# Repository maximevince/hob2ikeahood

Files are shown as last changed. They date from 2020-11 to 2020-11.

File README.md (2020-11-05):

# hob2ikeahood

## What is it?

AEG hob2hood support for Ikea Underverk Hoods

AEG hob2hood sends infrared codes from the hob in your kitchen to the hood on top of it.
E.g. AEG IKB84401FB supports this. (https://www.aeg.co.uk/kitchen/cooking/hobs/induction-hob/ikb84401fb/)

I do not have the appropriate AEG hood, that supports the hob2hood function, but rather a cheaper Ikea "Underverk"
(https://www.ikea.com/gb/en/p/underverk-built-in-extractor-hood-stainless-steel-50392326/)

## How does it work?

This project consists of a small PCB with some Arduino firmware, which will add hob2hood support to the Ikea Underverk.
It can be connected to sit in between the existing mainboard, and the buttons PCB. This way, no existing functionality is compromised.
You can still use the manual buttons, if you'd like to.

This is what the PCB looks like:

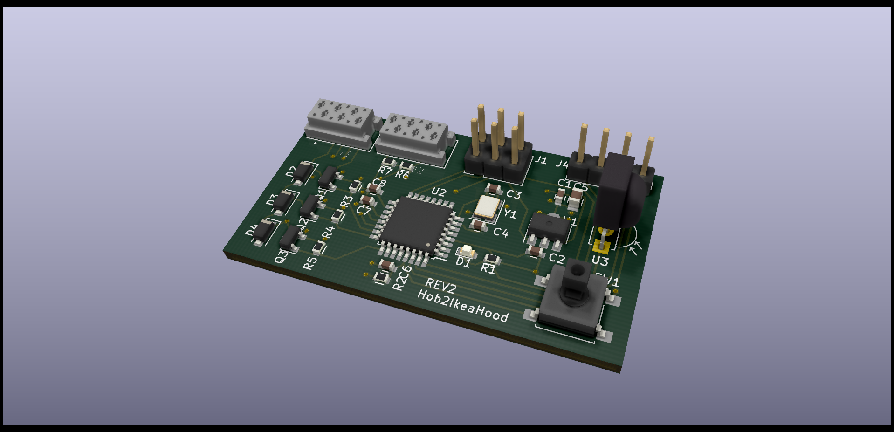
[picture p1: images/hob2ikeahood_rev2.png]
hob2ikeahood rev2 PCB


And this is what it looks like, when installed:

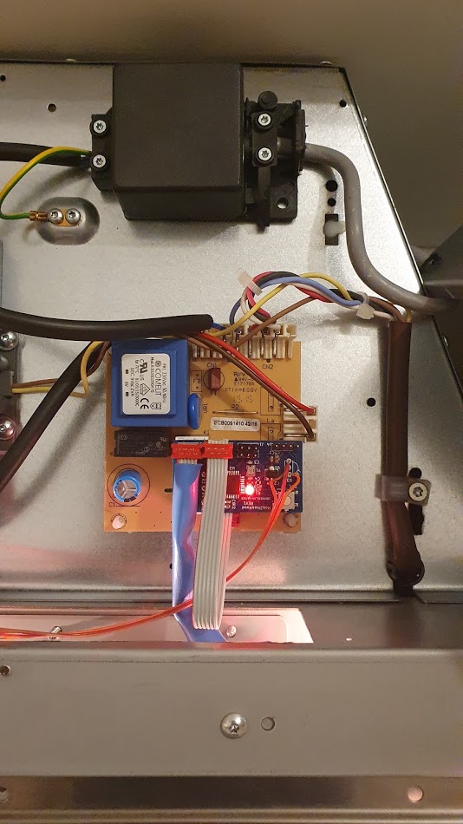
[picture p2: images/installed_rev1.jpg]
hob2ikeahood rev1 installed


A bit closer:

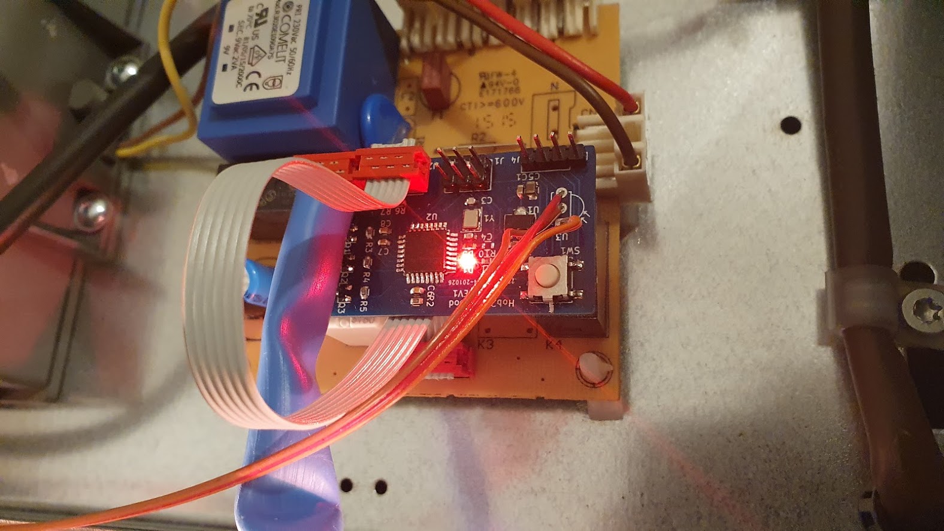
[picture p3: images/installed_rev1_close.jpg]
hob2ikeahood rev1 close-up


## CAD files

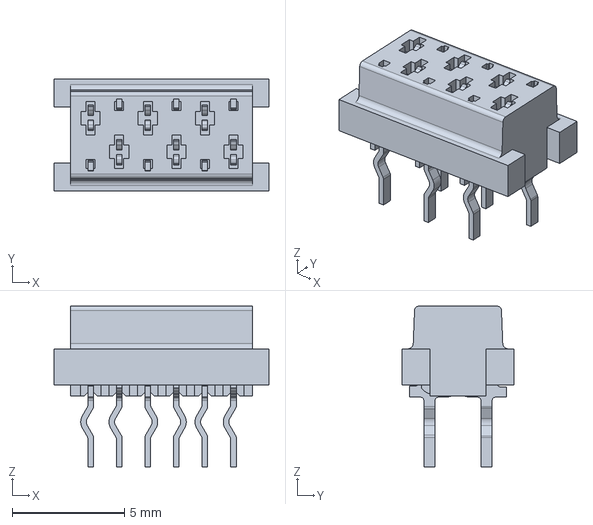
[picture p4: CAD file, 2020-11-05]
hardware/hob2hood.3dmodels/c-215079-6-t-3d.stp
9.56 x 5.00 x 7.15 mm

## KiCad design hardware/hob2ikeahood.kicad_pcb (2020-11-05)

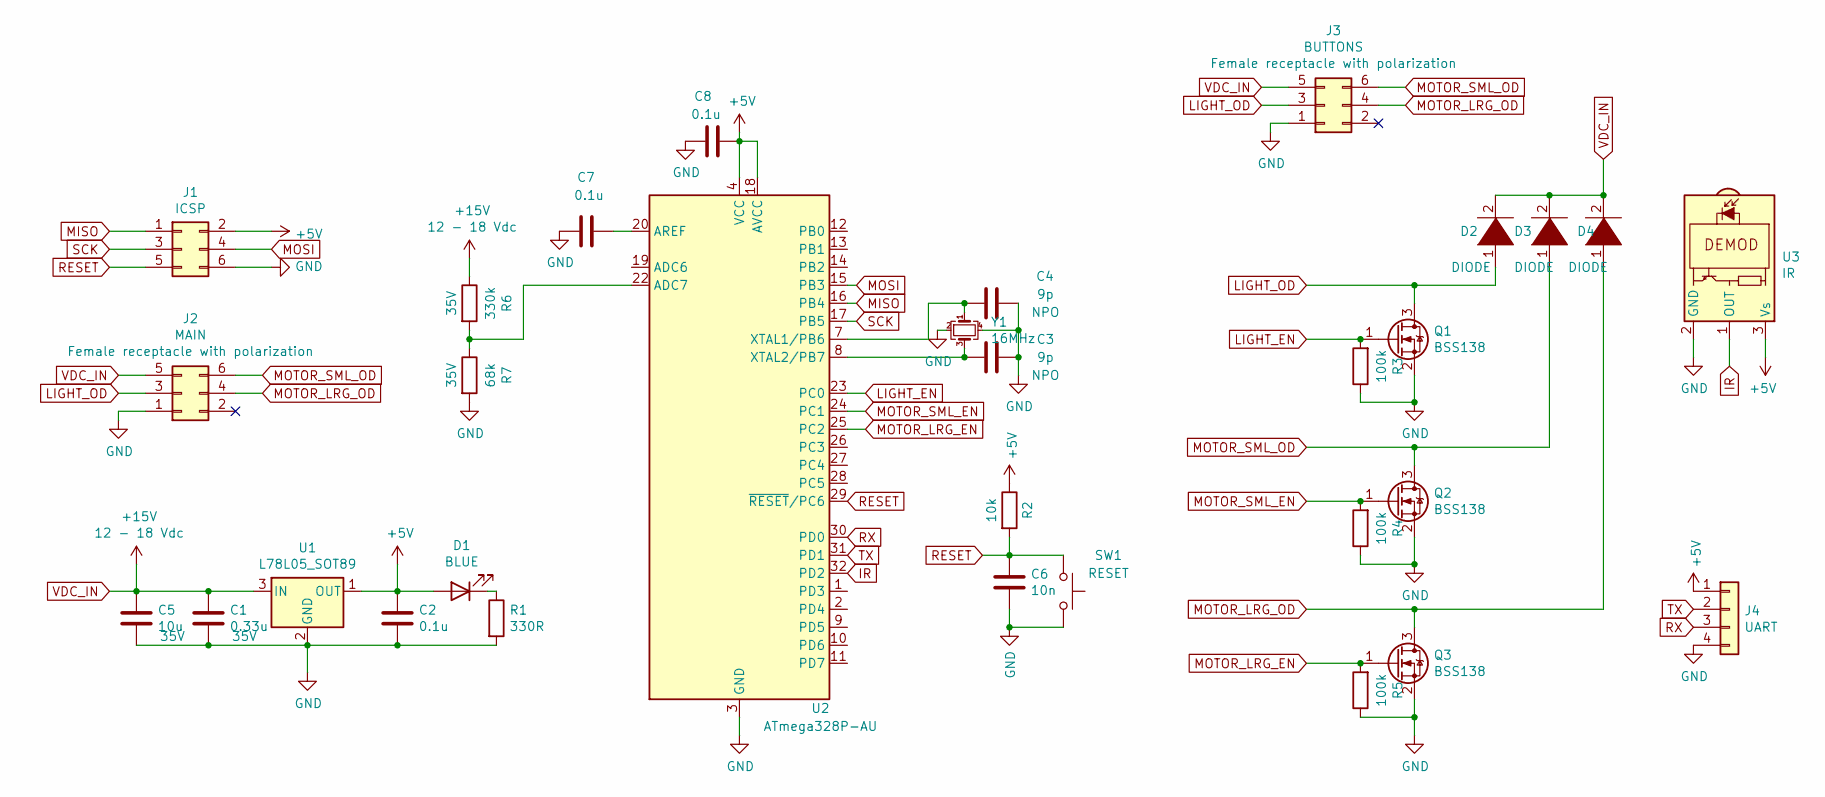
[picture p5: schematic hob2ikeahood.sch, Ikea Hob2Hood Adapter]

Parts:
C1: 0.33u; C_0603; Voltage rating 35V
C2, C7, C8: 0.1u; C_0603
C3, C4: 9p; C_0603
C5: 10u; C_0805; Voltage rating 35V
C6: 10n; C_0603
D1: BLUE; LED_0603
D2, D3, D4: DIODE; D_SOD-123F; Voltage rating 35V
J1: ICSP; Pin_Header_Straight_2x03_Pitch2.54mm
J2: MAIN; TE_215079-6
J3: BUTTONS; TE_215079-6
J4: UART; Pin_Header_Straight_1x04_Pitch2.54mm
Q1, Q2, Q3: BSS138; SOT-23
R1: 330R; R_0603
R2: 10k; R_0603
R3, R4, R5: 100k; R_0603
R6: 330k; R_0603; Voltage rating 35V
R7: 68k; R_0603; Voltage rating 35V
SW1: RESET; SW_SPST_B3S-1000
U1: L78L05_SOT89; SOT-89-3
U2: ATmega328P-AU; TQFP-32_7x7mm_Pitch0.8mm
U3: IR; IRReceiver_Vishay_MINICAST-3pin
Y1: 16MHz; Crystal_SMD_3225-4pin_3.2x2.5mm

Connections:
+5V: C2.1, C8.1, D1.2 (A), J1.2, J4.1, R2.1, U1.1 (OUT), U2.4 (VCC), U2.6 (VCC), U2.18 (AVCC), U3.3 (Vs)
GND: C1.2, C2.2, C3.2, C4.1, C5.2, C6.2, C7.2, C8.2, J1.6, J2.1, J3.1, J4.4, Q1.2 (S), Q2.2 (S), Q3.2 (S), R1.2, R3.1, R4.1, R5.1, R7.2, SW1.2, U1.2 (GND), U2.3 (GND), U2.5 (GND), U2.21 (GND), U3.2 (GND), Y1.2, Y1.4
IR: U2.32 (PD2), U3.1 (OUT)
LIGHT_EN: Q1.1 (G), R3.2, U2.23 (PC0)
LIGHT_OD: D2.1 (K), J2.3, J3.3, Q1.3 (D)
MISO: J1.1, U2.16 (PB4)
MOSI: J1.4, U2.15 (PB3)
MOTOR_LRG_EN: Q3.1 (G), R5.2, U2.25 (PC2)
MOTOR_LRG_OD: D4.1 (K), J2.4, J3.4, Q3.3 (D)
MOTOR_SML_EN: Q2.1 (G), R4.2, U2.24 (PC1)
MOTOR_SML_OD: D3.1 (K), J2.6, J3.6, Q2.3 (D)
unnamed: C3.1, U2.8 (XTAL2/PB7), Y1.3
unnamed: C4.2, U2.7 (XTAL1/PB6), Y1.1
unnamed: C7.1, U2.20 (AREF)
unnamed: D1.1 (K), R1.1
unnamed: R6.2, R7.1, U2.22 (ADC7)
RESET: C6.1, J1.5, R2.2, SW1.1, U2.29 (~RESET~/PC6)
RX: J4.3, U2.30 (PD0)
SCK: J1.3, U2.17 (PB5)
TX: J4.2, U2.31 (PD1)
VDC_IN: C1.1, C5.1, D2.2 (A), D3.2 (A), D4.2 (A), J2.5, J3.5, R6.1, U1.3 (IN)

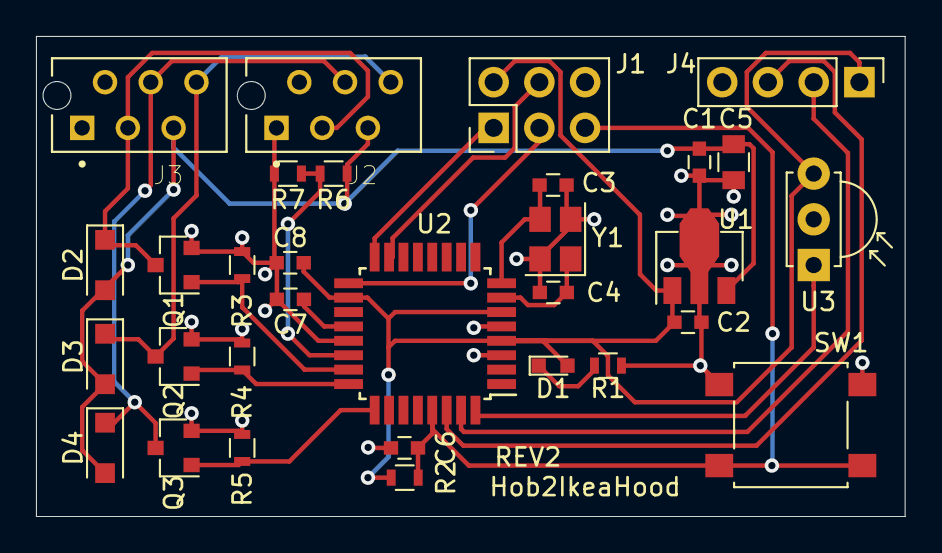
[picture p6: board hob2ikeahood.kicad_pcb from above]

Board: 2 copper layers, 48.3 x 26.7 mm, 31 parts (0 on the bottom side), 21 nets.

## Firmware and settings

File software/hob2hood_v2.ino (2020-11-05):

#include <IRremote.h>

// Pins for the output which control the MOSFETs, which control the relays
const int PIN_OUT_LIGHT = A0;
const int PIN_OUT_VENT_1 = A1;
const int PIN_OUT_VENT_2 = A2;


// IR commands from AEG hob2hood device
const long IRCMD_VENT_1 = 0xE3C01BE2;     //Hob2hood On (level 1)
const long IRCMD_VENT_2 = 0xD051C301;     //Hob2hood level 2
const long IRCMD_VENT_3 = 0xC22FFFD7;     //Hob2hood level 3
const long IRCMD_VENT_4 = 0xB9121B29;     //Hob2hood level 4
const long IRCMD_VENT_OFF = 0x55303A3;    //Hob2hood off
const long IRCMD_LIGHT_ON = 0xE208293C;   //Light on (Hood on)
const long IRCMD_LIGHT_OFF = 0x24ACF947;  //Light off (Automatic after 2min)

// IR Receiver config
const int PIN_IR_RECEIVER = 2;
IRrecv irrecv(PIN_IR_RECEIVER);
decode_results results;

#define ON HIGH
#define OFF LOW

// ventilation, light and mode status init
int ventilation = 0;
int last_ventilation = 0;
int light = 0;
int last_light = 0;

void setup() {
  Serial.begin(115200); // for serial monitor output
  Serial.println("Hob2Hood Starting ...");

  // Setup relay-outputs
  Serial.println("Setup Open Drain Outputs...");
  pinMode(PIN_OUT_VENT_1, OUTPUT);
  pinMode(PIN_OUT_VENT_2, OUTPUT);
  pinMode(PIN_OUT_LIGHT, OUTPUT);
  digitalWrite(PIN_OUT_VENT_1, OFF);
  digitalWrite(PIN_OUT_VENT_2, OFF);
  digitalWrite(PIN_OUT_LIGHT, OFF);

  Serial.println("Setup IR receiver");
  irrecv.enableIRIn(); // Start the IR receiver

  Serial.println("Hob2Hood ready!");

}

// Receive and decode IR commands and control hood upon received command
void loop() {
  if (irrecv.decode(&results)) {
    Serial.println(results.value, HEX); //Show raw data
    switch (results.value) {
      case IRCMD_LIGHT_ON:
        light = 1;
        Serial.println("IRCMD_LIGHT_ON");
        digitalWrite(PIN_OUT_LIGHT, ON);
        delay(1000);
        break;

      case IRCMD_LIGHT_OFF:
        light = 0;
        Serial.println("IRCMD_LIGHT_OFF");
        digitalWrite(PIN_OUT_LIGHT, OFF);
        delay(1000);
        break;

      case IRCMD_VENT_1:
        ventilation = 1;
        Serial.println("IRCMD_VENT_1");
        digitalWrite(PIN_OUT_VENT_1, ON);
        digitalWrite(PIN_OUT_VENT_2, OFF);
        break;

      case IRCMD_VENT_2:
        ventilation = 2;
        Serial.println("IRCMD_VENT_2");
        digitalWrite(PIN_OUT_VENT_1, OFF);
        digitalWrite(PIN_OUT_VENT_2, ON);
        break;

      case IRCMD_VENT_3:
        ventilation = 3;
        Serial.println("IRCMD_VENT_3");
        digitalWrite(PIN_OUT_VENT_1, ON);
        digitalWrite(PIN_OUT_VENT_2, ON);
        break;

      case IRCMD_VENT_4:
        ventilation = 4;
        Serial.println("IRCMD_VENT_4");
        digitalWrite(PIN_OUT_VENT_1, ON);
        digitalWrite(PIN_OUT_VENT_2, ON);
        break;

      case IRCMD_VENT_OFF:
        ventilation = 0;
        Serial.println("IRCMD_VENT_OFF");
        digitalWrite(PIN_OUT_VENT_1, OFF);
        digitalWrite(PIN_OUT_VENT_2, OFF);
        delay(1000);
        break;

      default:
        break;
    }
    irrecv.resume();
  }
}
